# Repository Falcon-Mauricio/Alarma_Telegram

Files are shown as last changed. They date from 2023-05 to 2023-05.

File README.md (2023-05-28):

# Alarma_Telegram
Repositorio dedicado al desarrollo de una alarma wifi que envia mensajes por "Telegram" cuando el sensor PIR detecta un movimiento

Se trata de un dispositivo de seguridad que utiliza un sensor PIR para vigilar constantemente el área en la que se enfoca. Cuando detecta movimiento, el microcontrolador seleccionado (en este caso, el ESP8266) que está conectado al sensor, envía un mensaje al usuario a través de un BOT de Telegram que le advierte de la activación. Al mismo tiempo, el buzzer se activa intermitentemente para simular una alarma.

Alarma_WIFI_telegram

Este dispositivo es una solución efectiva para la seguridad en el hogar o en cualquier área en la que se requiera una vigilancia constante. Además, la integración con el BOT de Telegram permite una rápida notificación al usuario en caso de una posible intrusión o actividad sospechosa.

Es importante destacar que, aunque este dispositivo es una medida de seguridad efectiva, no es la única. Es recomendable complementarlo con otras medidas de seguridad, como cerraduras de alta seguridad, iluminación adecuada, y alarmas de seguridad adicionales.
En general, este dispositivo es una solución práctica y de bajo costo para aumentar la seguridad en cualquier área donde se requiera una vigilancia constante.

Archivos Inlcuidos:
- Diseño del Circuito Impreso
- Diseño del Modelo 3D
- Código para la vinculación con Telegram

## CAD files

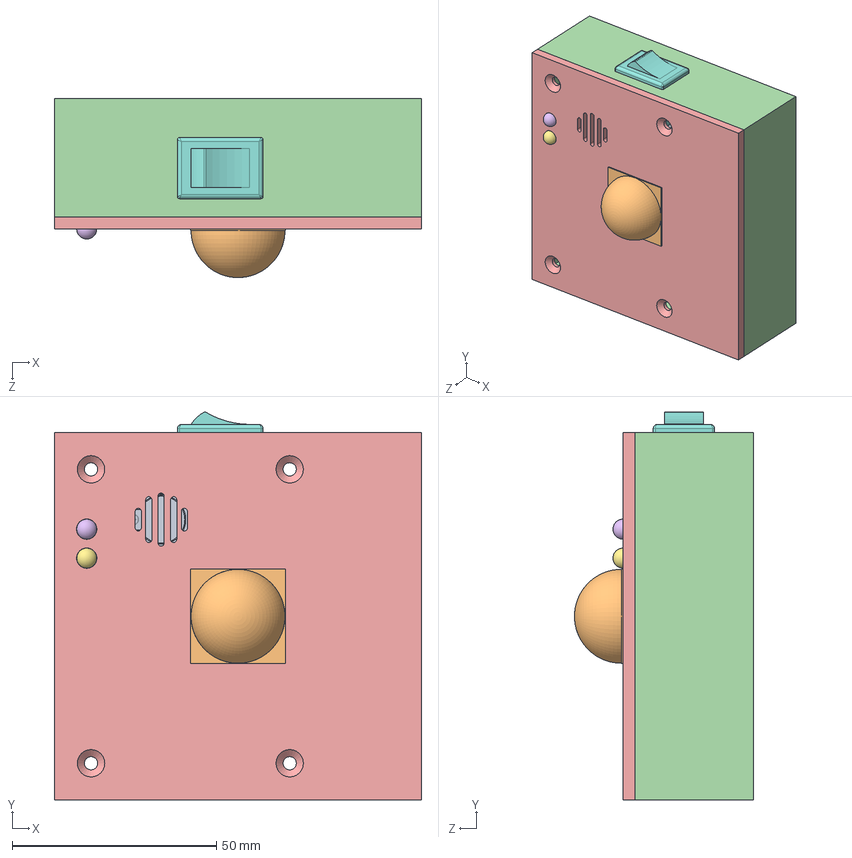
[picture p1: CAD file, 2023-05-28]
Diseño_Chasis_3D/Alarma_WIFI.SLDASM
90.0 x 95.0 x 43.9 mm
PCB_MainBoard_ESP8266
PIR-HC_SR501
18650_Holder
Base_Chasis
Tapa
LED_D5.0mm.step
LED_D5.0mm_Clear.step
Tecla_llave

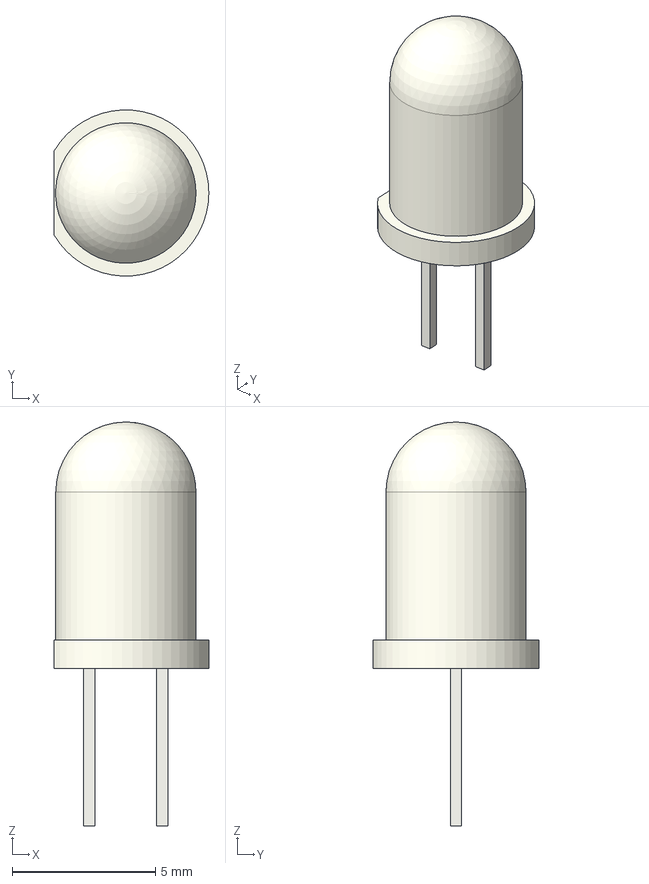
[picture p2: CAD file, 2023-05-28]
Diseño_Chasis_3D/LED_D5.0mm_Clear.step
5.40 x 5.79 x 14.1 mm

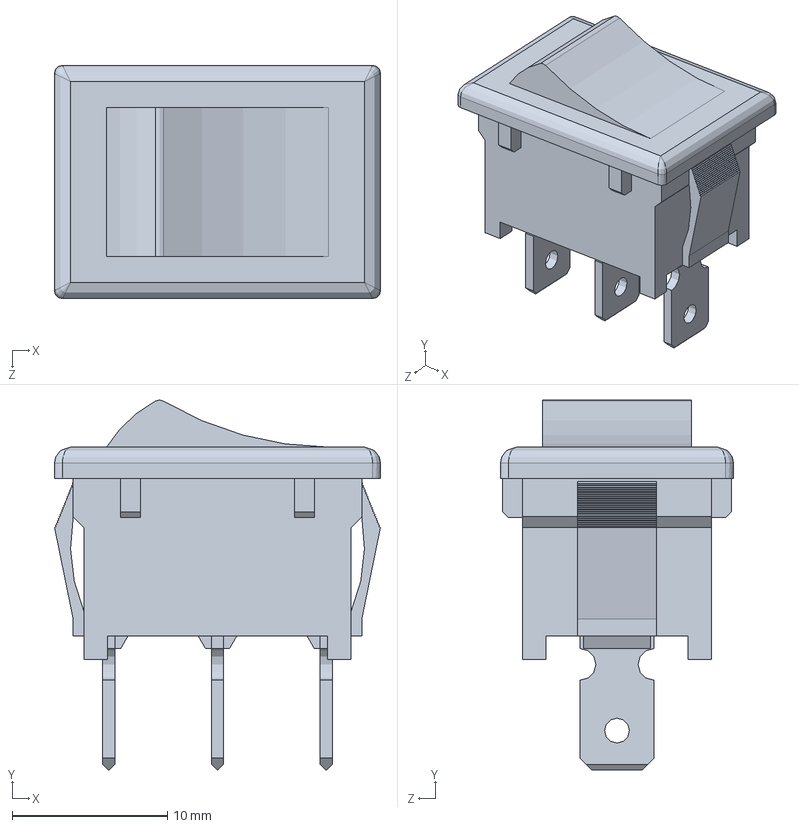
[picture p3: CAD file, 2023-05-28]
Diseño_Chasis_3D/Tecla_llave.SLDPRT
21.0 x 23.8 x 15.0 mm

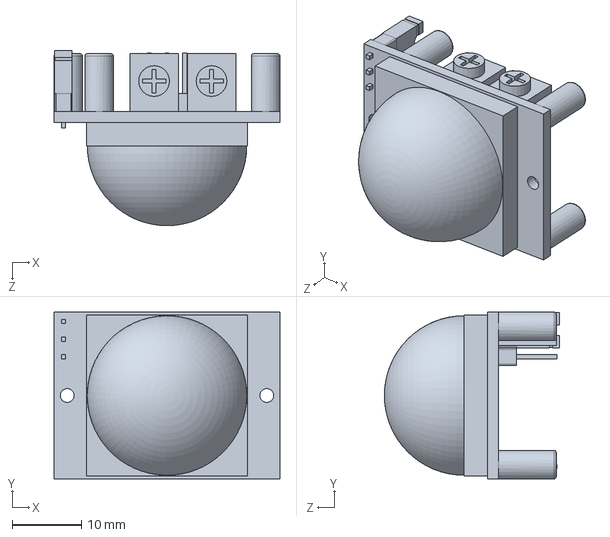
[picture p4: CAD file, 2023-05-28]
Diseño_Chasis_3D/PIR-HC_SR501.SLDPRT
32.6 x 24.1 x 25.3 mm

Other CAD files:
Diseño_Chasis_3D/Base_Chasis.SLDPRT
Diseño_Chasis_3D/LED_D5.0mm.step
Diseño_Chasis_3D/Tapa.SLDPRT

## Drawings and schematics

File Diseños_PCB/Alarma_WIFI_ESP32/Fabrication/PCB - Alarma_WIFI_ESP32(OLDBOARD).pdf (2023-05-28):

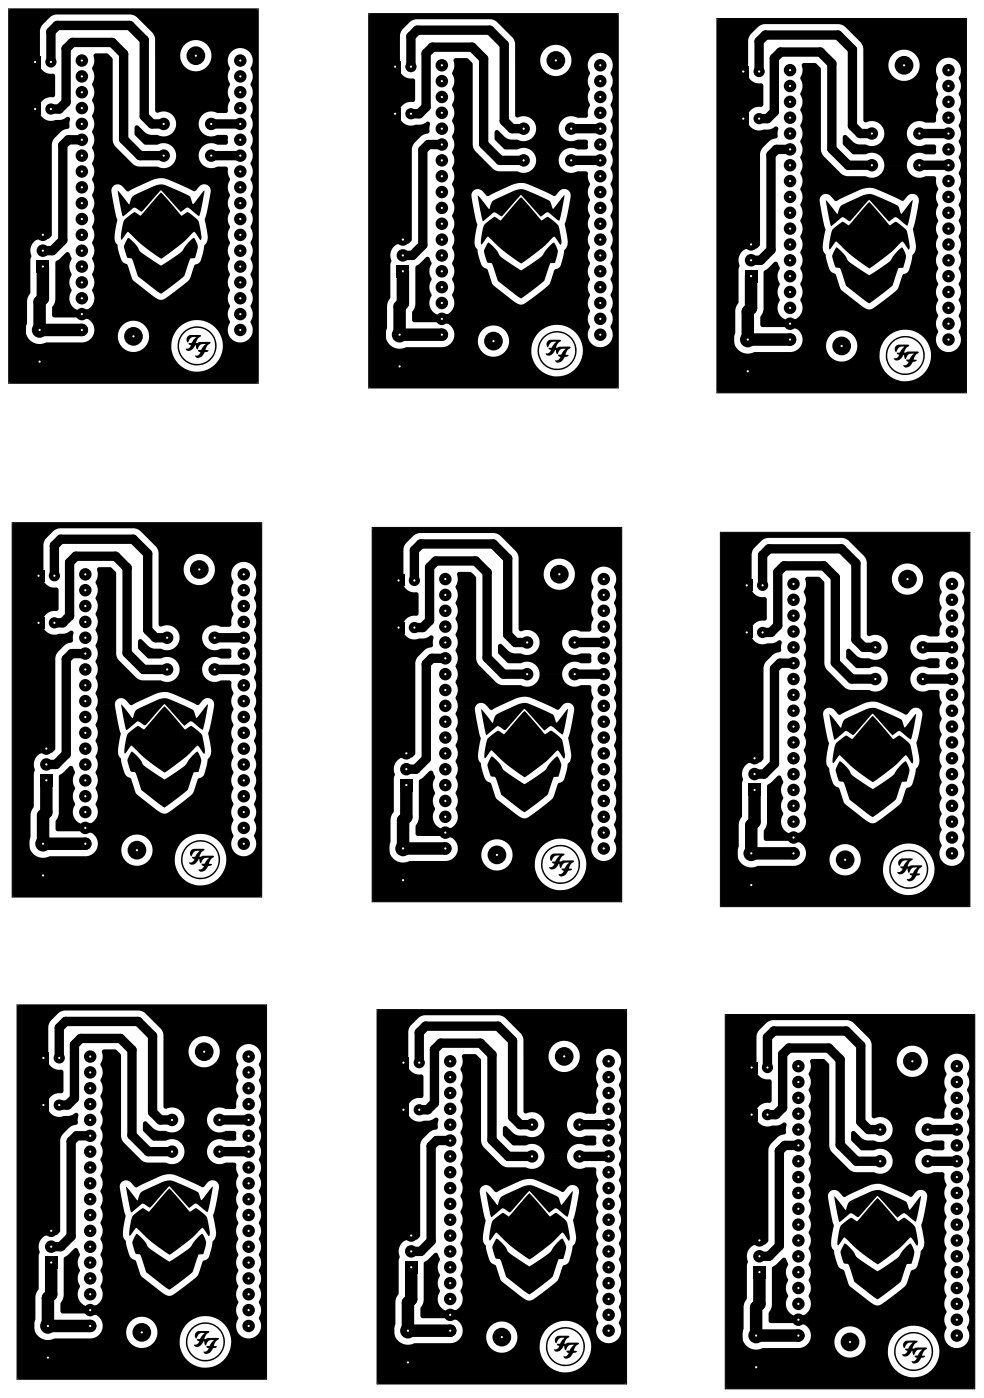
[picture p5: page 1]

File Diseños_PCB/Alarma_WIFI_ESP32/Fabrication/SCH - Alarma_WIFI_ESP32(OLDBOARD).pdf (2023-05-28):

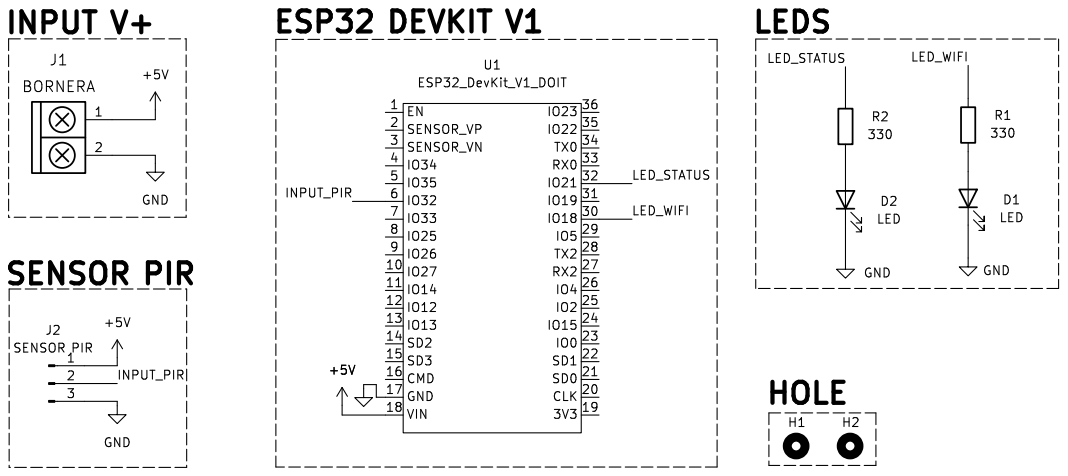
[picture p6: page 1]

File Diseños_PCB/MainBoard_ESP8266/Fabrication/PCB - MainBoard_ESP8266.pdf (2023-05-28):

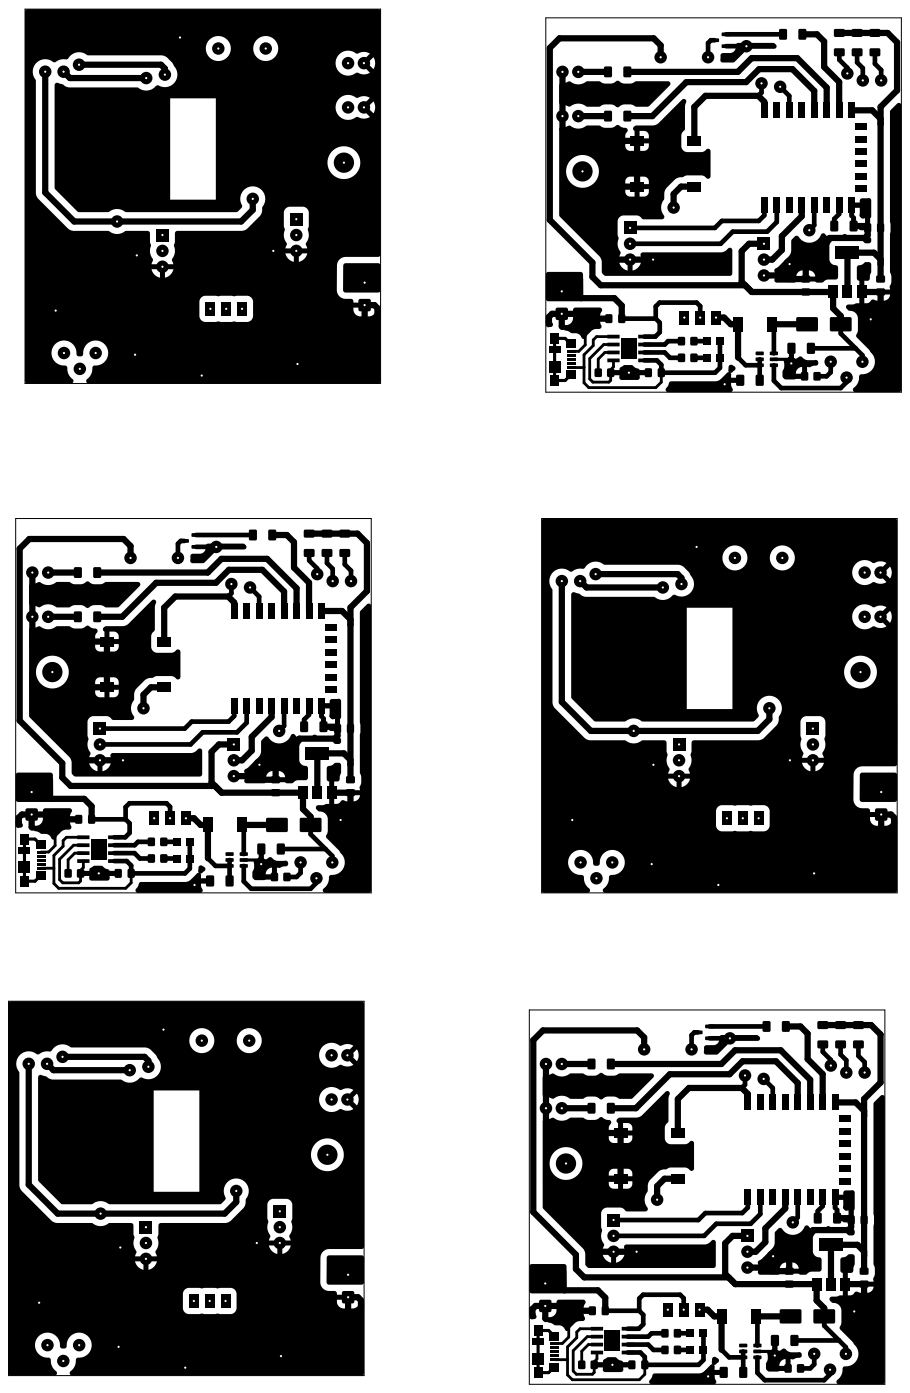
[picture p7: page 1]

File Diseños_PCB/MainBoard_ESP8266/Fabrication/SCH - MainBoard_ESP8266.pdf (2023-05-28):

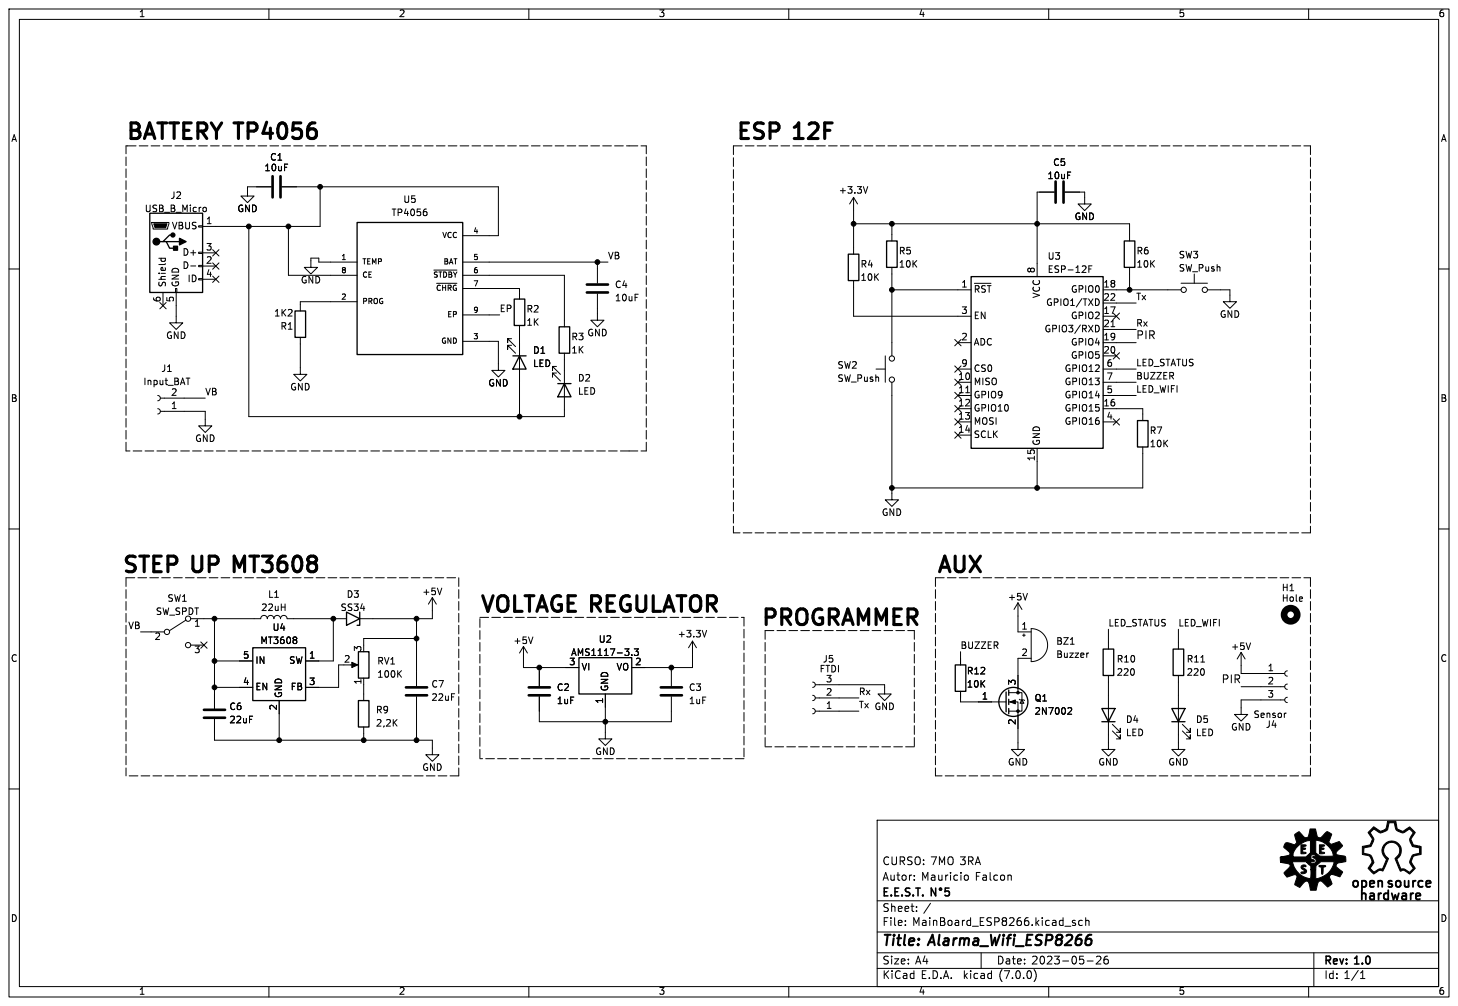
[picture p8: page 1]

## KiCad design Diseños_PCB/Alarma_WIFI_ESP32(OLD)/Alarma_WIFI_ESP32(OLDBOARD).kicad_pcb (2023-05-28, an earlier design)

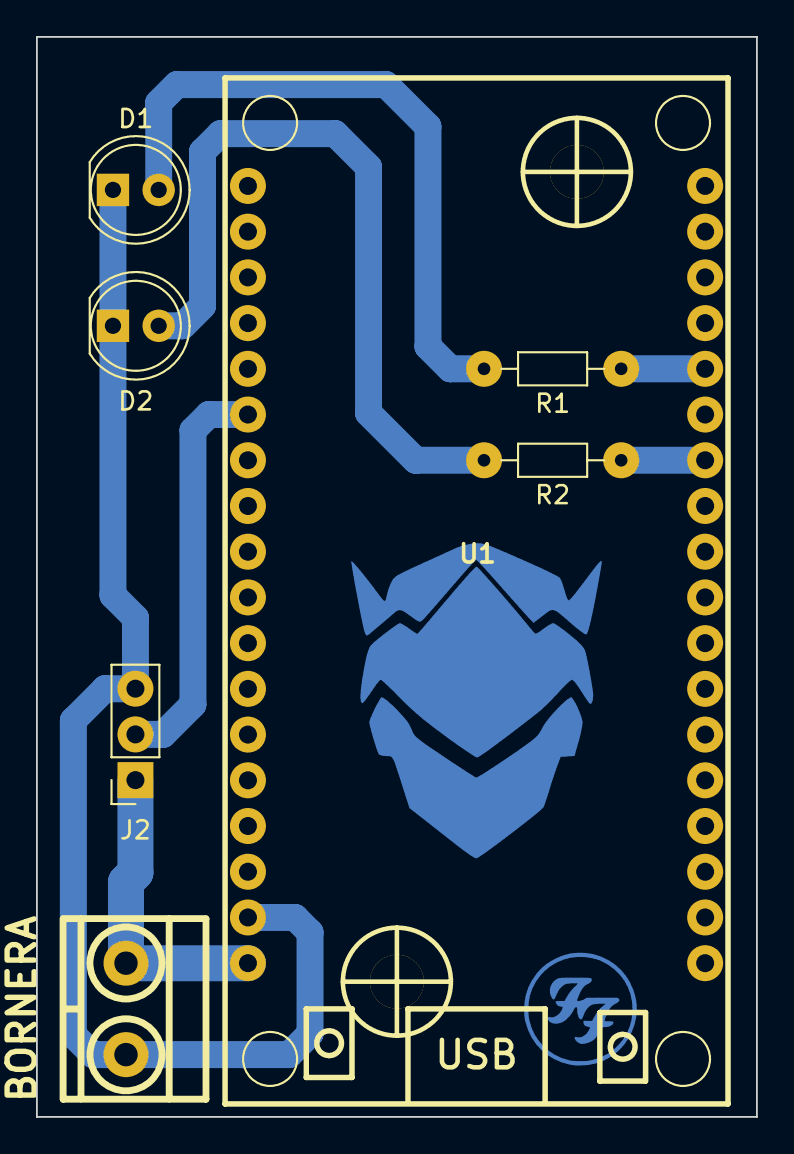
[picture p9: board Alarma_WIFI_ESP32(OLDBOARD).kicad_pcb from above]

Board: 2 copper layers, 40.0 x 60.0 mm, 9 parts (0 on the bottom side), 7 nets.

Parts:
D1, D2: LED; LED_D5.0mm
H1, H2: MountingHole; hole_3mm
J1: BORNERA; BORNERA2_AZUL
J2: SENSOR PIR; PinSocket_1x03_P2.54mm_Vertical
R1, R2: 330; R_Axial_DIN0204_L3.6mm_D1.6mm_P7.62mm_Horizontal
U1: ESP32_DevKit_V1_DOIT; ESP32_DEVKIT_V1_DOIT

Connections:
+5V: J1.1, J2.1, U1.18 (VIN)
/INPUT_PIR: J2.2, U1.6 (IO32)
/LED_1: R1.1, U1.32 (IO21)
/LED_2: R2.1, U1.30 (IO18)
GND: D1.1 (K), D2.1 (K), J1.2, J2.3, U1.17 (GND)
unnamed: D1.2 (A), R1.2
unnamed: D2.2 (A), R2.2

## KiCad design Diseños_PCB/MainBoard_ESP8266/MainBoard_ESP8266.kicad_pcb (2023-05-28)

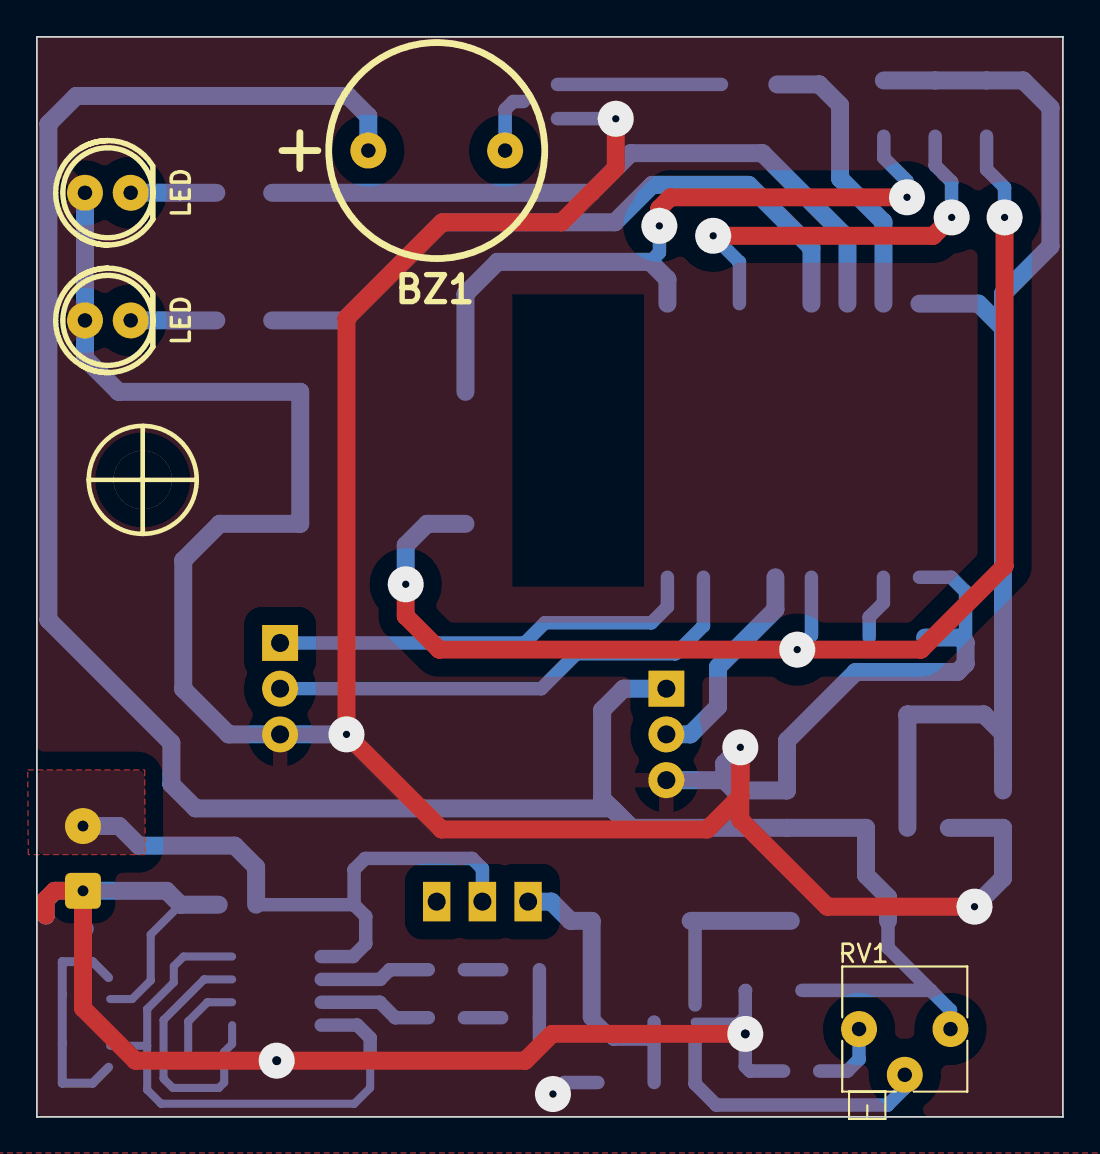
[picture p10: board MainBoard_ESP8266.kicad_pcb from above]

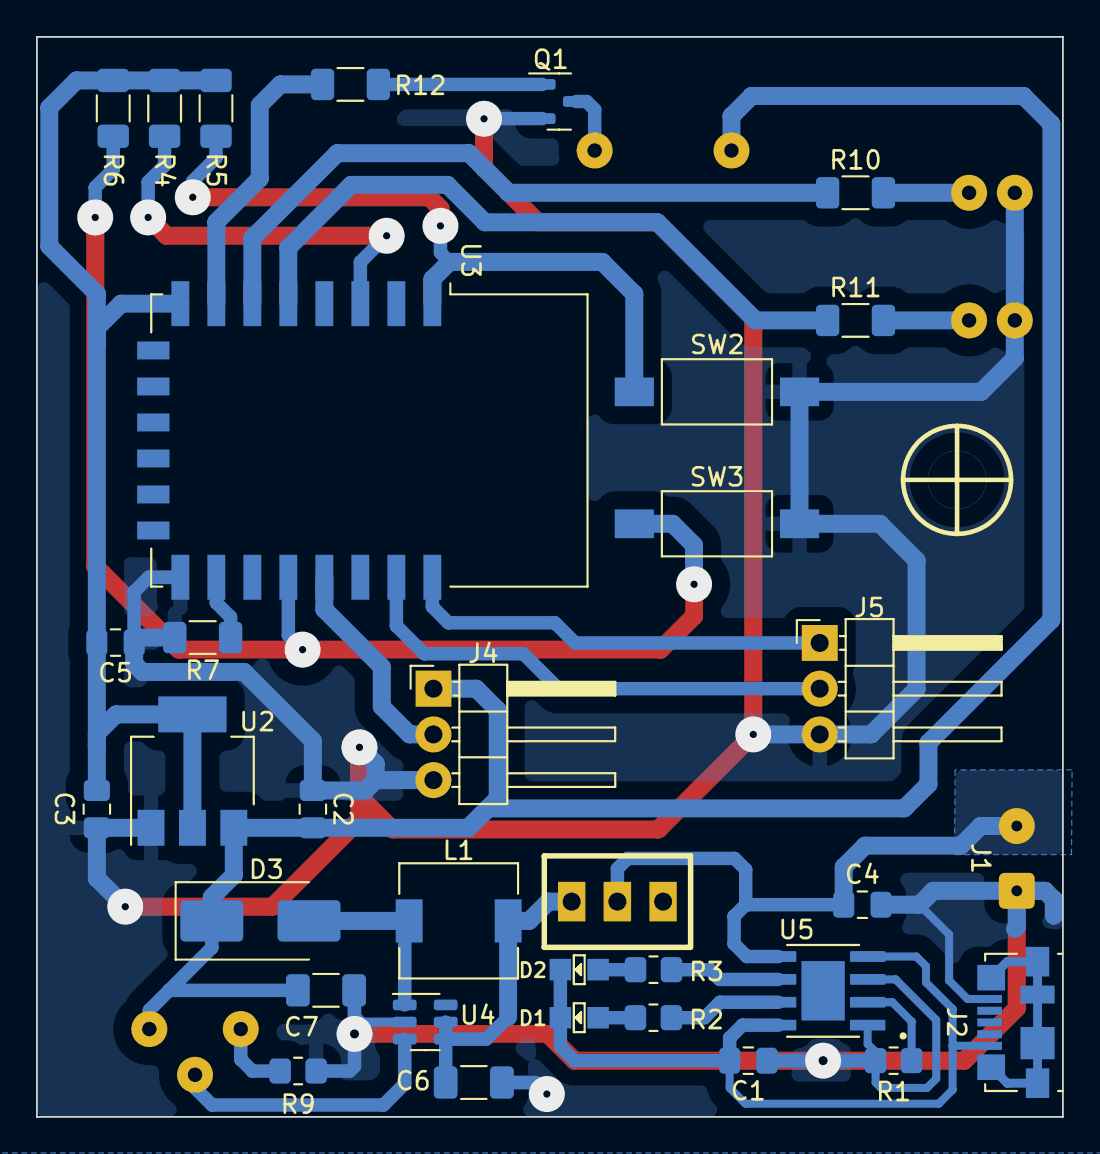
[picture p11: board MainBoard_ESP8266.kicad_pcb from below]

Board: 2 copper layers, 57.0 x 60.0 mm, 39 parts (34 on the bottom side), 28 nets.

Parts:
BZ1: Buzzer; Buzzer_12mm
C1, C4, C5: 10uF; C_0805_2012Metric_Pad1.18x1.45mm_HandSolder
C2, C3: 1uF; C_0805_2012Metric_Pad1.18x1.45mm_HandSolder
C6, C7: 22uF; C_1206_3216Metric_Pad1.33x1.80mm_HandSolder
D1, D2: LED; Led_0805
D3: SS34; D_SMB_Handsoldering
D4: LED; led_5mm_red
D5: LED; led_5mm_green
H1: Hole; Separador_M3_5mm
J1: Input_BAT; SolderWire-0.1sqmm_1x02_P3.6mm_D0.4mm_OD1mm
J2: USB_B_Micro; USB_Micro-B_Molex_47346-0001
J4: Sensor; PinHeader_1x03_P2.54mm_Horizontal
J5: FTDI; PinHeader_1x03_P2.54mm_Horizontal
L1: 22uH; L_6.3x6.3_H3
Q1: 2N7002; SOT-23
R1: 1K2; R_0805_2012Metric_Pad1.20x1.40mm_HandSolder
R2, R3: 1K; R_0805_2012Metric_Pad1.20x1.40mm_HandSolder
R4, R5, R6, R7, R12: 10K; R_1206_3216Metric_Pad1.30x1.75mm_HandSolder
R9: 2,2K; R_0805_2012Metric_Pad1.20x1.40mm_HandSolder
R10, R11: 220; R_1206_3216Metric_Pad1.30x1.75mm_HandSolder
RV1: 100K; Potentiometer_Bourns_3266P_Horizontal
SW1: SW_SPDT; SW_SPDT_TH_100Mils_VERTICAL
SW2, SW3: SW_Push; SW_SPST_FSMSM
U2: AMS1117-3.3; SOT-223-3_TabPin2
U3: ESP-12F; ESP-12E
U4: MT3608; SOT-23-6
U5: TP4056; SOP127P600X175-9N

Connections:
+3.3V: C3.1, C5.2, R4.1, R5.1, R6.1, U2.2 (VO), U3.8 (VCC)
+5V: BZ1.1 (-), C2.1, C7.1, D3.1 (A1), J4.1, RV1.3, U2.3 (VI)
/BUZZER: R12.1, U3.7 (GPIO13)
/LED_STATUS: R10.1, U3.6 (GPIO12)
/LED_WIFI: R11.1, U3.5 (GPIO14)
/PIR: J4.2, U3.19 (GPIO4)
/Rx: J5.2, U3.21 (GPIO3/RXD)
/Tx: J5.1, U3.22 (GPIO1/TXD)
/VB: C4.1, J1.2, SW1.2 (B), U5.5 (BAT)
GND: C1.1, C2.2, C3.2, C4.2, C5.1, C6.2, C7.2, D4.1 (K), D5.1 (K), J1.1, J2.5 (GND), J4.3, J5.3, Q1.2 (S), R1.1, R7.2, R9.2, SW2.1, SW3.2, U2.1 (GND), U3.15 (GND), U4.2 (GND), U5.1 (TEMP), U5.3 (GND)
unnamed: BZ1.2 (+), Q1.3 (D)
unnamed: C1.2, D1.2 (A), D2.2 (A), J2.1 (VBUS), U5.4 (VCC), U5.8 (CE)
unnamed: D1.1 (K), R2.2
unnamed: D2.1 (K), R3.2
unnamed: D3.2 (A2), L1.2, U4.1 (SW)
unnamed: D4.2 (A), R10.2
unnamed: D5.2 (A), R11.2
unnamed: Q1.1 (G), R12.2
unnamed: R9.1, RV1.1
unnamed: C6.1, L1.1, SW1.1 (A), U4.4 (EN), U4.5 (IN)
unnamed: R4.2, U3.3 (EN)
unnamed: R6.2, SW3.1, U3.18 (GPIO0)
unnamed: R7.1, U3.16 (GPIO15)
unnamed: R5.2, SW2.2, U3.1 (~RST)
unnamed: RV1.2, U4.3 (FB)
unnamed: R1.2, U5.2 (PROG)
unnamed: R2.1, U5.7 (~CHRG)
unnamed: R3.1, U5.6 (~STDBY)

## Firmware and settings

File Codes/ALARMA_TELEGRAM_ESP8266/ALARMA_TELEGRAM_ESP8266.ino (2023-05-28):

#include <ESP8266WiFi.h>
#include <UniversalTelegramBot.h>
#include <ArduinoJson.h>

#define LED_STATUS 12
#define LED_WIFI 14
#define BUZZER 13
#define PIR 4

const char* ssid = "Nombre_de_tu_red";       // Nombre de tu red WiFi
const char* password = "Contraseña_de_tu_red"; // Contraseña de tu red WiFi

// Inicializar BOT Telegram
#define BOTtoken "Token"  // Tu Bot Token (Obtener de Botfather)
// Usa @myidbot para averiguar el chat ID
// Tambien necesita hacer click en "start" antes de  enviarle mensajes el bot
#define CHAT_ID "ID"

WiFiClientSecure client;
UniversalTelegramBot bot(BOTtoken, client);
bool motionDetected = false;

// Indica cuando se detecta movimiento
void IRAM_ATTR detectsMovement() {
  motionDetected = true;
}

void handleNewMessages(int numNewMessages) {

  for (int i = 0; i < numNewMessages; i++) {
    String chat_id = String(bot.messages[i].chat_id);
    if (chat_id != CHAT_ID) {
      bot.sendMessage(chat_id, "Usuario No Autorizado", "");
      continue;
    }

    String text = bot.messages[i].text;

    if (text == "/alarma_on") {
      bot.sendMessage(chat_id, "Alarma activada", "");
      digitalWrite(LED_STATUS, HIGH);
    }

    if (text == "/alarma_off") {
      bot.sendMessage(chat_id, "Alarma desactivada", "");
      digitalWrite(LED_STATUS, LOW);
    }
  }
}

void setup() {
  Serial.begin(115200);
  // Configura el pin PIR como entrada pull-up
  pinMode(PIR, INPUT_PULLUP);
  pinMode(BUZZER, OUTPUT);
  pinMode(LED_WIFI, OUTPUT);
  pinMode(LED_STATUS, OUTPUT);
  digitalWrite(LED_WIFI, LOW);
  for (int i = 0; i < 2; i++) {
      digitalWrite(LED_STATUS, HIGH); // Enciende el LED
      delay(500);
      digitalWrite(LED_STATUS, LOW); // Apaga el LED
      delay(500);
    }
  // Configure el pin PIR como interrupción, asigne la función de interrupción y configure el modo RISING
  attachInterrupt(digitalPinToInterrupt(PIR), detectsMovement, RISING);
  Serial.print("Conectando a la red WiFi: ");
  Serial.println(ssid);
  WiFi.begin(ssid, password);

  while (WiFi.status() != WL_CONNECTED) {
    Serial.print(".");
    digitalWrite(LED_WIFI, LOW);
    delay(500);
  }
  Serial.println("");
  Serial.println("WiFi conectado");
  digitalWrite(LED_WIFI, HIGH);
  Serial.print("Dirección IP asignada: ");
  Serial.println(WiFi.localIP());
  bot.sendMessage(CHAT_ID, "Bot iniciado", "");
}

void loop() {
  int numNewMessages = bot.getUpdates(bot.last_message_received + 1);

  while (numNewMessages) {
    handleNewMessages(numNewMessages);
    numNewMessages = bot.getUpdates(bot.last_message_received + 1);
  }

  if (motionDetected) {
    bot.sendMessage(CHAT_ID, "¡Movimiento detectado!", "");
    for (int i = 0; i < 10; i++) {
      digitalWrite(BUZZER, HIGH); // Enciende el BUZZER
      delay(500);
      digitalWrite(BUZZER, LOW); // Apaga el BUZZER
      delay(500);
    }
    motionDetected = false;
  }
}

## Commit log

2023-05-25 Creacion de los archivos del PCB
    [Main_ESP32_DEVKIT_V1.kicad_pcb, Main_ESP32_DEVKIT_V1.kicad_sch]
2023-05-26 Agregado los archivos del sensor PIR y PCB's
    [MainBoard_ESP32Module.kicad_pcb, MainBoard_ESP32Module.kicad_sch, MainBoard_ESP8266.kicad_pcb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]
2023-05-27 Edicion archivos pcb
    [MainBoard_ESP8266.kicad_sch]
2023-05-27 Diseño del esquematico terminado
    [MainBoard_ESP8266.kicad_pcb, MainBoard_ESP8266.kicad_sch]
2023-05-28 Actualizacion PCB
    [MainBoard_ESP8266.kicad_pcb, MainBoard_ESP8266.kicad_sch]
2023-05-28 Mejoras PCB
    [MainBoard_ESP8266.kicad_pcb, MainBoard_ESP8266.kicad_sch]
2023-05-28 Agregados los archivos viejos de pcbs, creacion del codigo
    [Alarma_WIFI_ESP32(OLDBOARD).kicad_pcb, Alarma_WIFI_ESP32(OLDBOARD).kicad_sch, MainBoard_ESP32Module.kicad_pcb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]
2023-05-28 Edicion nombre de archivo
    [Alarma_WIFI_ESP32(OLDBOARD).kicad_pcb, Alarma_WIFI_ESP32(OLDBOARD).kicad_sch]
2023-05-28 Creacion del codigo funcional para el ESP8266
2023-05-28 Creacion del chasis de la alarma
    [Alarma_WIFI.SLDASM, Base_Chasis.SLDPRT, PIR-HC_SR501.SLDPRT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]
2023-05-28 Arreglos diseños 3D
    [Alarma_WIFI.SLDASM, Base_Chasis.SLDPRT, LED_D5.0mm.step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]
